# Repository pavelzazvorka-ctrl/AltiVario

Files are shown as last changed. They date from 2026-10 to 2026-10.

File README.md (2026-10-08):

# AltiVario

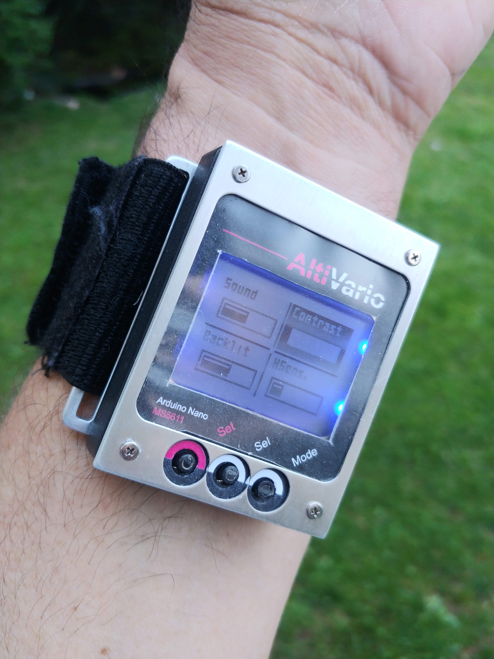
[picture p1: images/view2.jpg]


AltiVario je vario na paragliding. meri a zobrazuje rychlost stoupani/klesani, vysku a posila data pres BT do aplikace XC track na mobilnim telefonu

### Historie:

Cilem hry bylo mit rychle a presne zalozni vario s moznosti exportu zivych dat do aplikace XC track v mobilnim telefonu.
cela akce byla zaroven test mych moznosti a schopnosti zajistit kompletni short-run vyrobu jak HW tak SW. Vyrobil 
jsem celkem deset kusu, ktere jsem vetsinou rozdal znamym. AltiVario opravdu letalo a bylo prakticky pouzitelne.
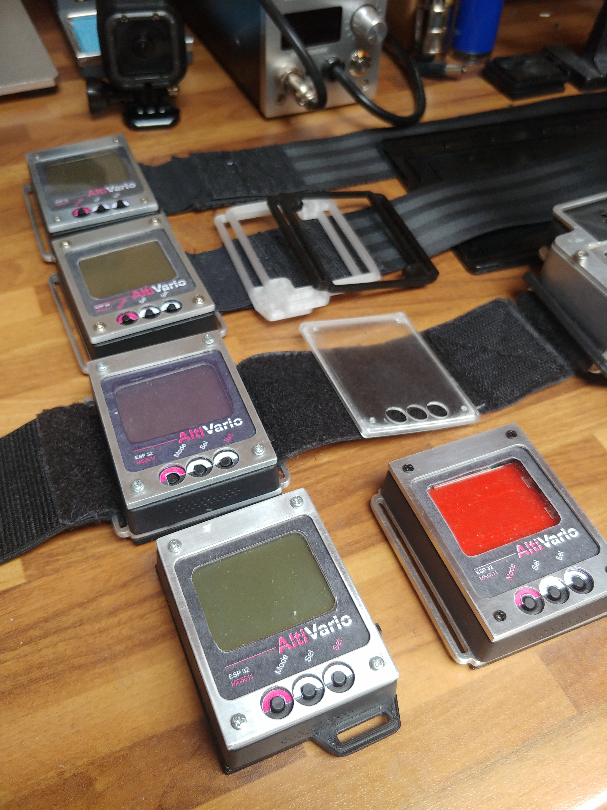
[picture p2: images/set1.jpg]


### HW

vario je postavene nad ESP32 a nejlepsim barometrickym sensorem na trhu MSI5611.Duraz byl kladen hlavne na minimalni
prodlevu a presnost. Soucasti repository jsou i data pro vyrobu PCB ( Eagle ) a CNC G-code data pro frezovani krabicek 
a duralovych ramecku.

Vyvoj byl uspesny, vyroba byla rozumne automatizovana, finalni cena jednoho kusu byla kolem 600 CZK ( viz xls ) 

### SW

Popis SW a celkove ovladani pristore je popsano v Vario.md
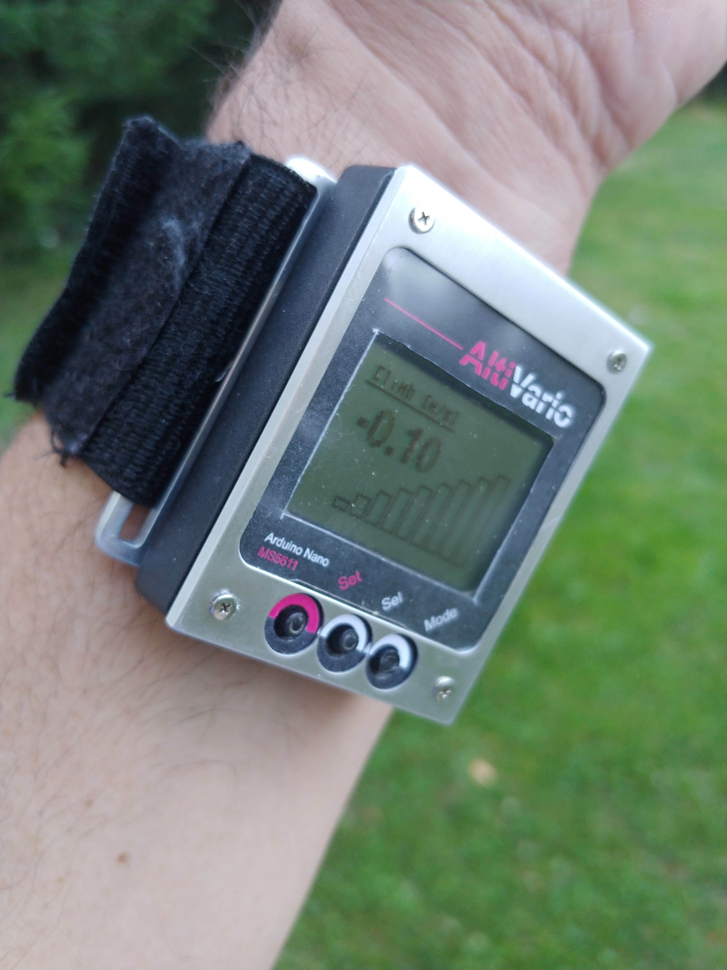
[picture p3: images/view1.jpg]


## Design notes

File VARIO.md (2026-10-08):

# AltiVario – návod k použití

*Pavel, 12. 10. 2021 · Původní dokumentace k verzi softwaru 0.61.*

Stručný návod k ovládání přístroje AltiVario, jeho nastavení, propojení s XCTrack a nabíjení.

> **Poznámka:** Popis odpovídá původní verzi 0.61 z roku 2021. Údaje o výdrži a dostupných funkcích se vztahují k této verzi.

## 1. Úvodní obrazovka a tlačítka

Úvodní obrazovka zobrazuje verzi softwaru a napětí LiPo článku. Na přístroji jsou tři tlačítka: **MODE**, **SEL** a **SET**.

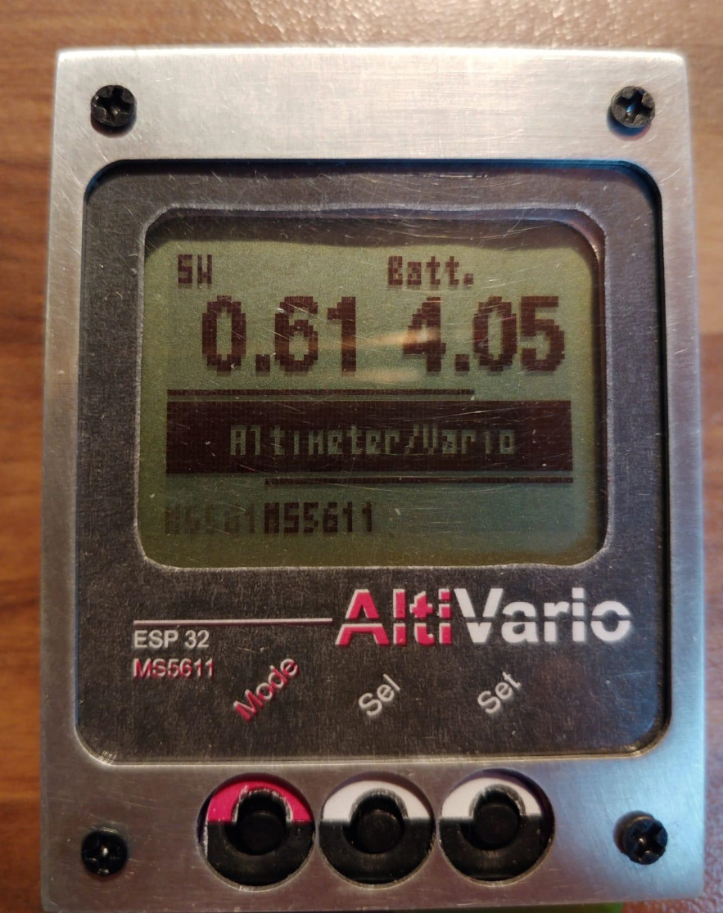
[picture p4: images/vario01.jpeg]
AltiVario – úvodní obrazovka


## 2. Provozní obrazovky

Jednotlivé provozní obrazovky se přepínají **krátkým stiskem MODE**.

### Obrazovka 1 – Výška, vário a graf (varianta 1)

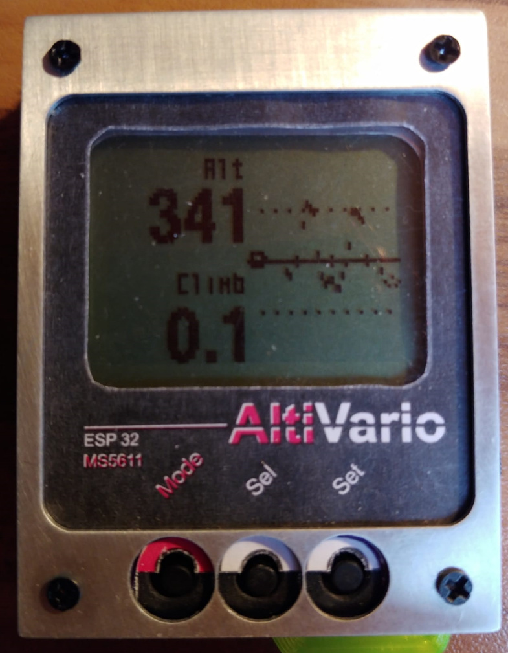
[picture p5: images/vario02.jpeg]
Výška, vário a graf – první rozložení


### Obrazovka 2 – Výška, vário a graf (varianta 2)

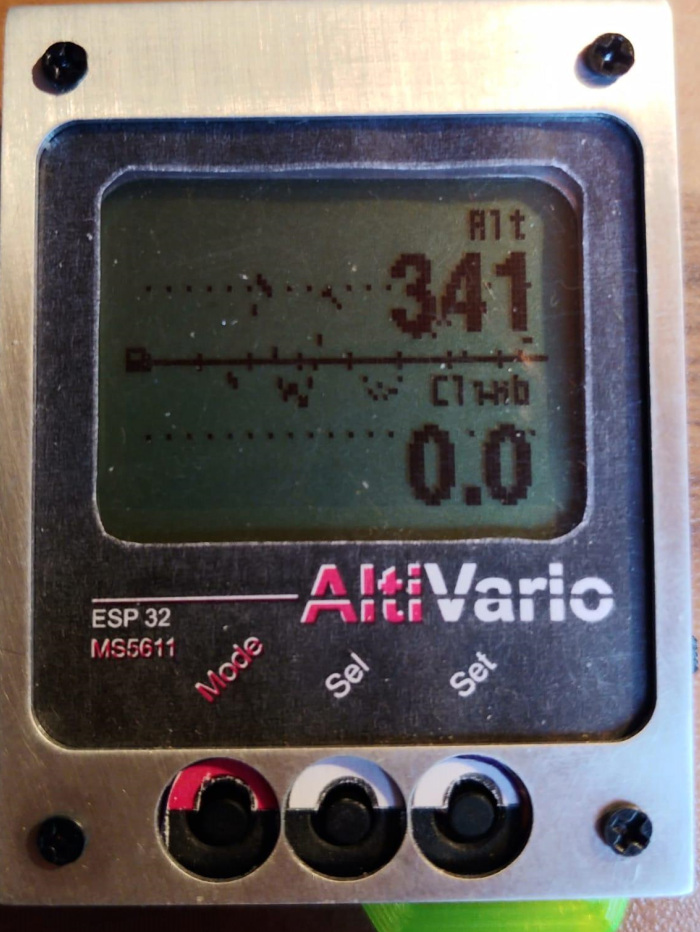
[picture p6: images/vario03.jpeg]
Výška, vário a graf – druhé rozložení


### Obrazovka 3 – Alt, Alt2, čas a vário

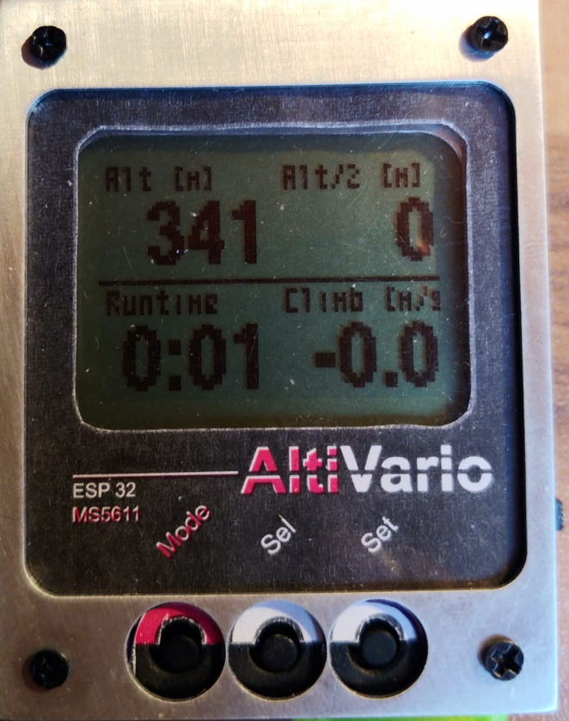
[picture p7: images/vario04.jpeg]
Alt, Alt2, čas a vário


Stisk **SET** na této obrazovce resetuje hodnotu **Alt2**. Typicky se používá k vynulování výšky na zemi.

### Obrazovka 4 – Alt, Alt3, výškový zisk a vário

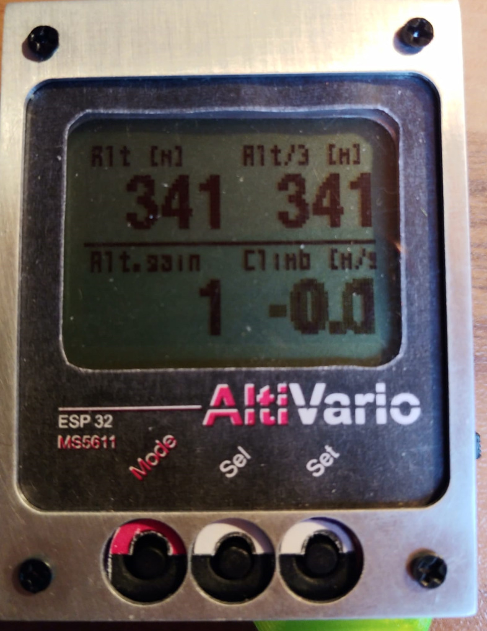
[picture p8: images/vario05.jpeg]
Alt, Alt3, výškový zisk a vário


Stisk **SET** na této obrazovce resetuje hodnotu **Alt3**. Typicky se používá při vlétnutí do stoupavého proudu.

### Obrazovka 5 – Teplota a baterie

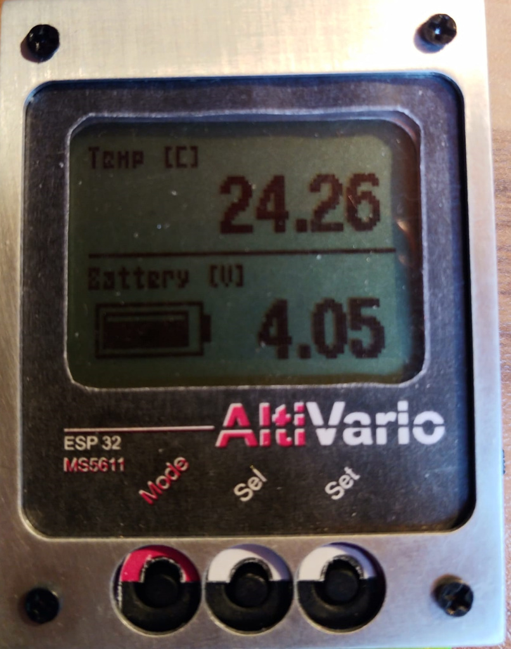
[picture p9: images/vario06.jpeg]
Teplota a napětí baterie


Dlouhým stiskem **SET** na této obrazovce se přístroj přepne do nabíjecího režimu. Změní se kalibrace měření napětí a vypne se zvuková signalizace. Zpět do běžného režimu se lze vrátit pouze vypnutím a opětovným zapnutím přístroje.

## 3. Nastavení

Do nastavení se vstupuje **dlouhým stiskem MODE**. Obsahuje dvě obrazovky, mezi nimiž se přepíná krátkým stiskem **MODE**. Dlouhý stisk **MODE** vrátí přístroj do hlavního režimu.

### 3.1 Referenční výška / tlak a hranice signalizace

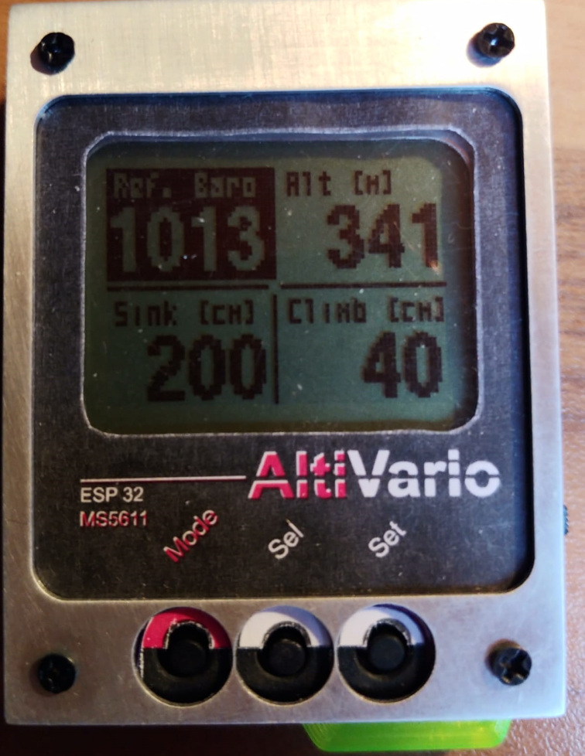
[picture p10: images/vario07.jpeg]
Nastavení referenčního tlaku, výšky a prahů stoupání/klesání


Na první obrazovce lze nastavit referenční tlak v hPa nebo referenční výšku v metrech a prahové hodnoty zvukové signalizace stoupání a klesání (**lift/sink**).

- **SEL** přepíná mezi nastavovanými položkami.
- **SET** zahajuje úpravu vybrané položky.
- Hodnoty se upravují po jednotlivých číslicích pomocí **SEL/SET**.

Příklad zobrazení při úpravě referenční výšky:

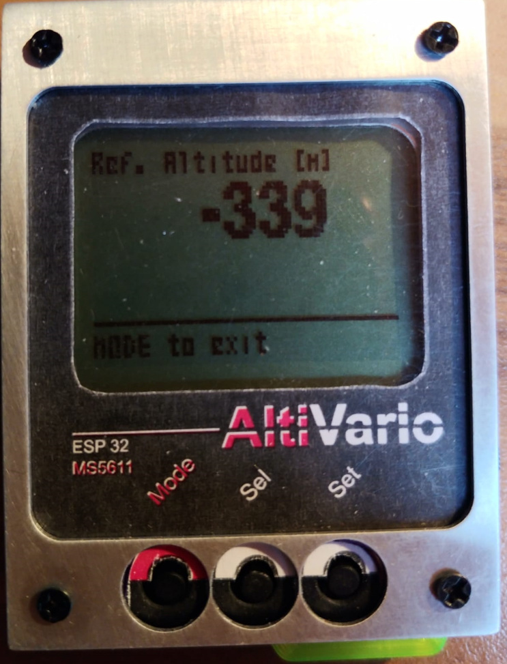
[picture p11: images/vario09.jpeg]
Úprava referenční výšky


### 3.2 Zvuk, kontrast, Bluetooth a citlivost

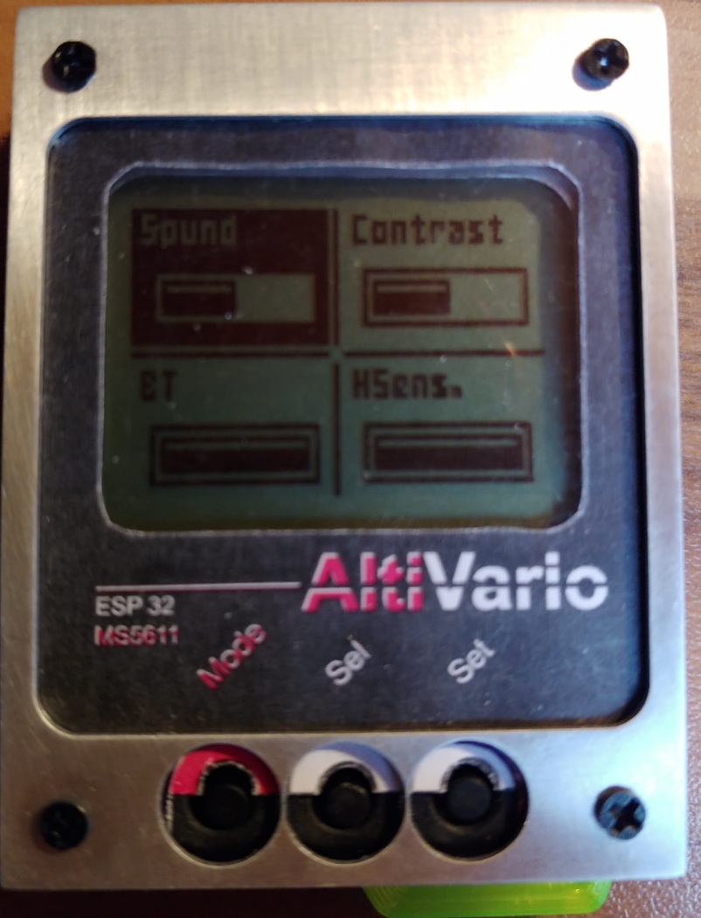
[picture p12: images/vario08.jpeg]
Nastavení zvuku, kontrastu, Bluetooth a citlivosti


Na druhé obrazovce jsou nastavení zobrazená jako posuvné pruhy. Pomocí **SEL** se vybere položka, pomocí **SET** se změní její hodnota.

| Položka | Význam |
| --- | --- |
| **Sound** | Tři režimy: `OFF`, `NORMAL`, `LIVELY AIR`. Poslední režim indikuje drobné pohyby vzduchu kolem nulového stoupání („poklepávání“). |
| **Contrast** | U použitého CZ displeje podle původního návodu nefunguje / není potřeba. |
| **BT** | Položka Bluetooth na obrazovce nastavení; původní text její ovládání blíže nepopisuje. |
| **HSens.** | Příprava na regulaci citlivosti; ve verzi 0.61 ještě není funkční. |

## 4. Propojení s XCTrack

1. V Bluetooth vyhledejte zařízení **BT AltiVario** a spárujte je bez zadání kódu.
2. V aplikaci **XCTrack** otevřete **Connection & Sensors** a vyberte **BT AltiVario**.
3. Zapněte volbu **Use external barometer**.
4. Položka **Calibrate** zobrazí hodnoty měřené variometrem.

V původním návodu je jako příklad uvedeno měření **330,835 ± 0,096 m**; autor tuto hodnotu srovnává s deklarovanou přesností použitého senzoru **MS5611** (přibližně 10 cm).

Doporučuje se přidat na hlavní obrazovku XCTrack údaj **Baro Alt** a před vzletem zkalibrovat tlak podle výšky místa startu.

## 5. Nabíjení

Původní konstrukce nemá automatickou správu nabíjení (*power management*). Nabíjení probíhá přes USB a vyžaduje **sledování napětí baterie**. Autor původního návodu doporučuje slabší napájecí zdroj.

1. Zapněte přístroj.
2. Pomocí **MODE** přejděte na obrazovku s baterií (obrazovka 5).
3. Podržte **SET**, dokud se nezobrazí nabíjecí režim.

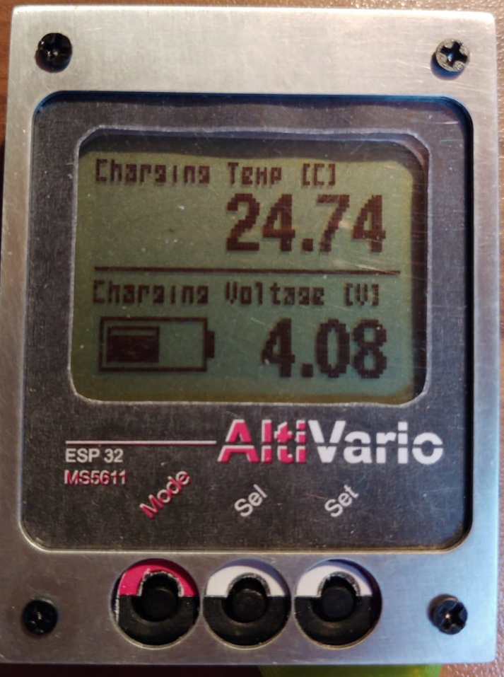
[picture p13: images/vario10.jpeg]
AltiVario – nabíjecí režim


V nabíjecím režimu odpovídá zobrazené napětí lépe skutečnému napětí článku a vário nevydává zvukové signály. Návrat do běžného režimu vyžaduje vypnutí a zapnutí přístroje.

> **Upozornění:** Nabíjecí režim nenahrazuje ochranu LiPo článku ani automatické ukončení nabíjení. Původní dokument výslovně uvádí, že přístroj nemá power management; nabíjení proto vyžaduje odpovídající bezpečné zapojení a dohled.

## 6. Hardware a výdrž

- **Displej:** Nokia
- **Barometrický senzor:** MS5611
- **Procesor:** ESP32 se sníženou frekvencí jádra kvůli spotřebě
- **Odhadovaná výdrž podle původního návodu:** přibližně 6 hodin s Bluetooth, déle bez Bluetooth; u větší baterie autor očekával přibližně 8 hodin.

Firmware verze **0.61** byl podle původního dokumentu dostupný ve zdrojových kódech a bylo jej možné aktualizovat přes USB. Původní Word obsahuje vložený objekt/ikonu ZIP archivu, nikoli ověřený odkaz na repozitář; odkaz na aktuální firmware je potřeba doplnit samostatně.

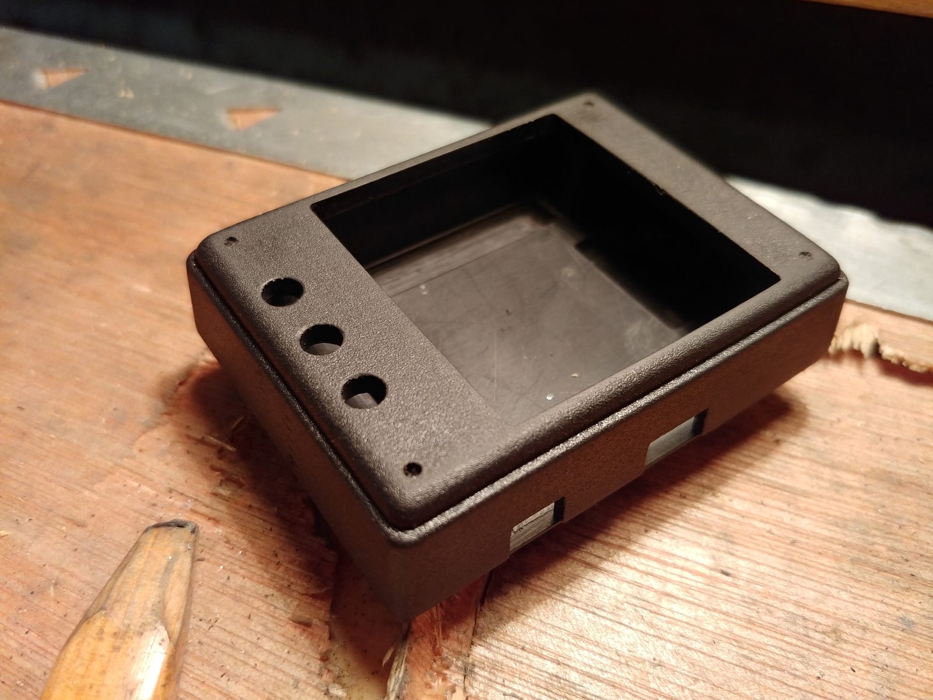
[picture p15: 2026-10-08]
doc/img/20210103_174444_HDR.jpg

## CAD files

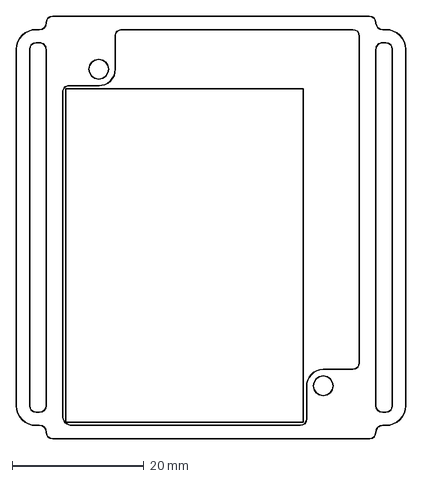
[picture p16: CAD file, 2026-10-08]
cnc/prezka 4.dxf
59.0 x 64.0 mm

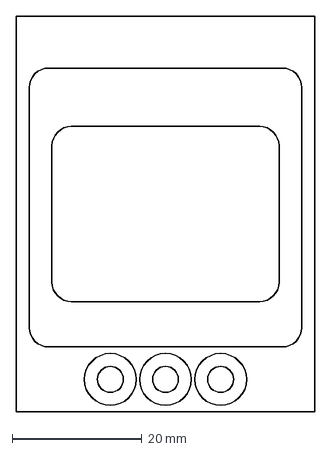
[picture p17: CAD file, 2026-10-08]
cnc/inlay.dxf
46.0 x 61.0 mm

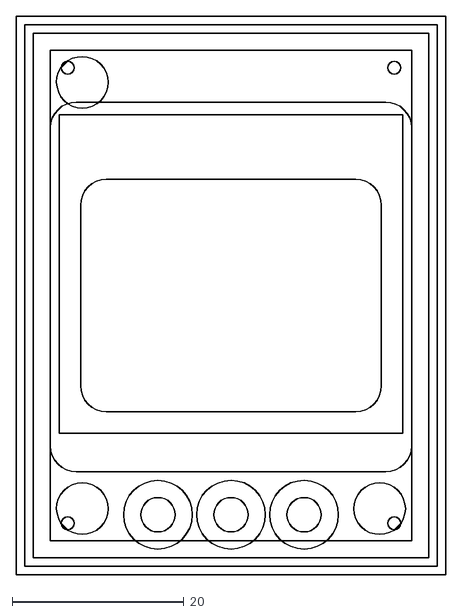
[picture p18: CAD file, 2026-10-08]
cnc/vario.dxf
50.0 x 65.0

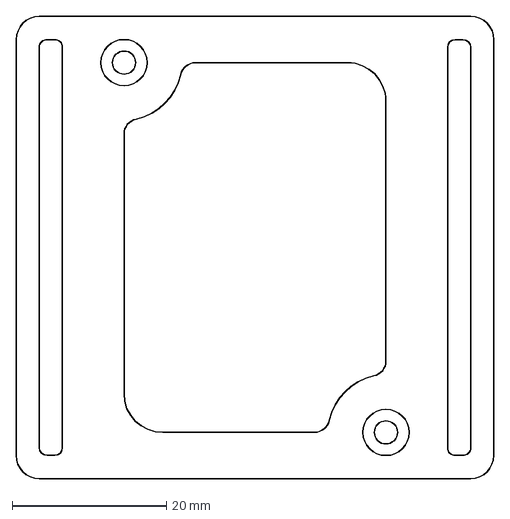
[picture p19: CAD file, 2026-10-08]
cnc/back.dxf
62.0 x 60.0 mm

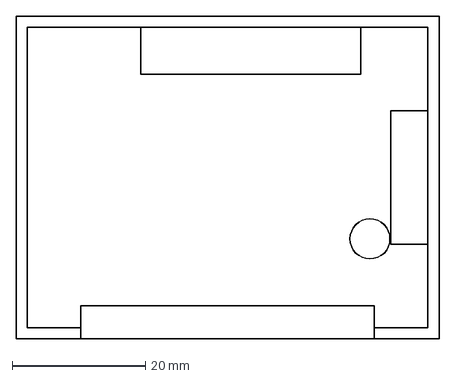
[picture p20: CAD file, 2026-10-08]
cnc/cover.dxf
63.4 x 48.4 mm

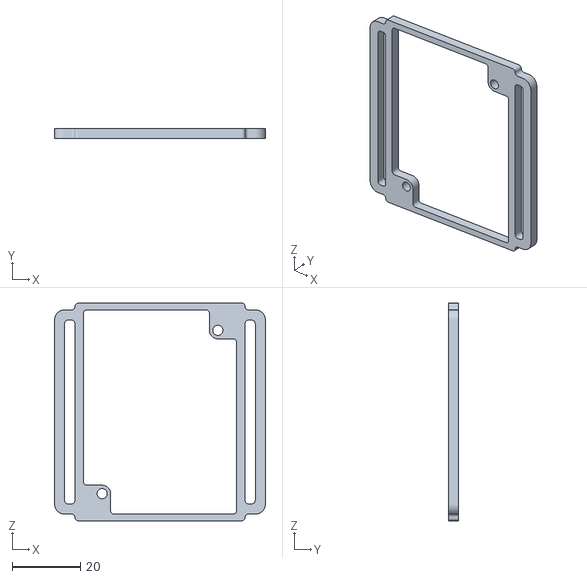
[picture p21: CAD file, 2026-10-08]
cnc/Prezka2.stl
62.0 x 3.00 x 64.0

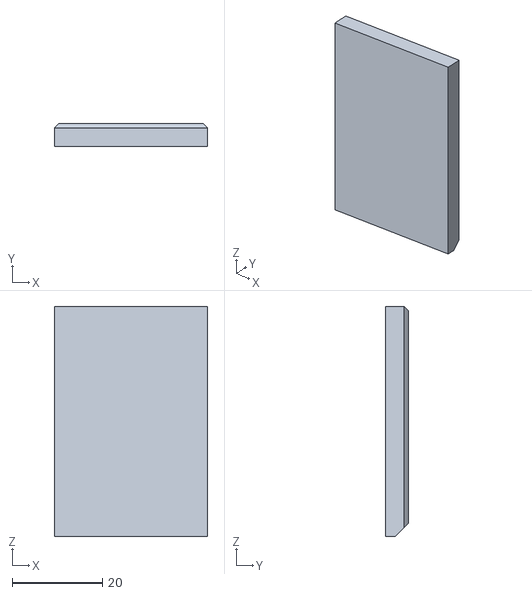
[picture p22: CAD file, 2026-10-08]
cnc/Accu.stl
34.0 x 5.20 x 51.0

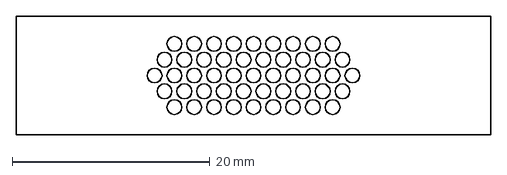
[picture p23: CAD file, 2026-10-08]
cnc/grill.dxf
48.0 x 12.0 mm

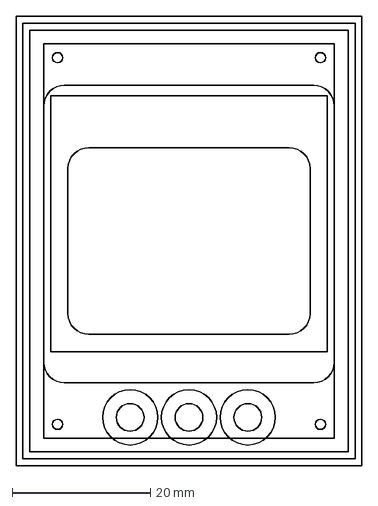
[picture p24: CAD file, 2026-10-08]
cnc/frame.dxf
50.0 x 65.0 mm

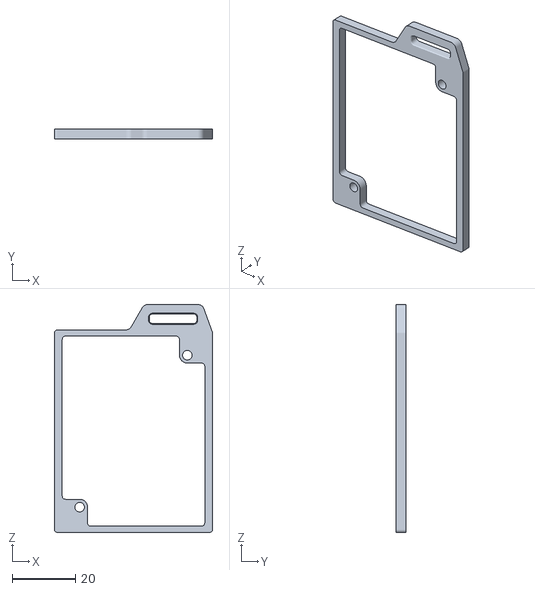
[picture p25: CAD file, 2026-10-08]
cnc/Prezka3.stl
50.0 x 3.00 x 72.0

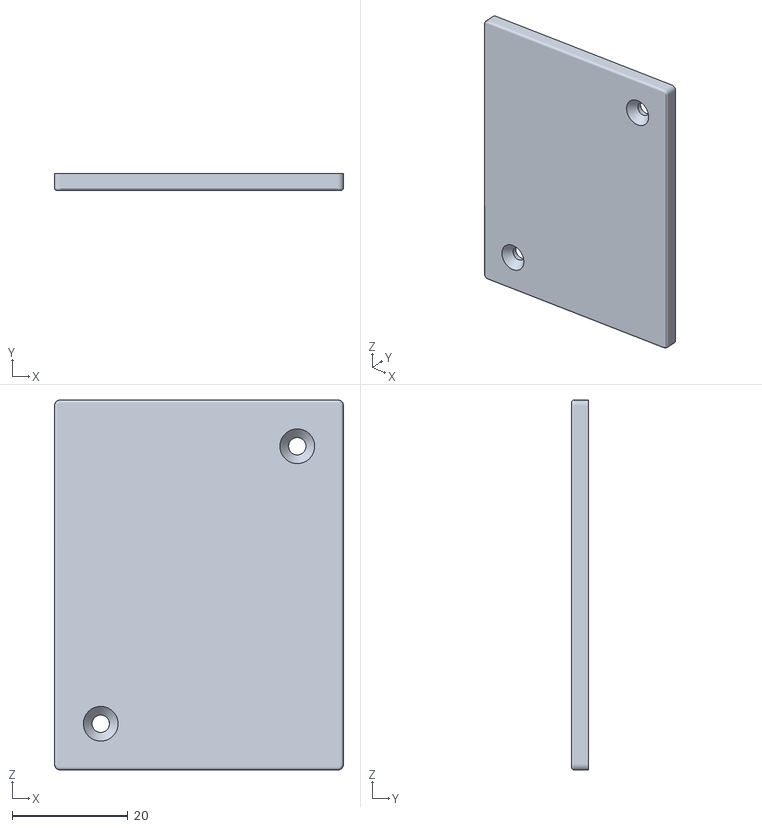
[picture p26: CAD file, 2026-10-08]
cnc/Deklik.stl
50.0 x 3.00 x 64.0

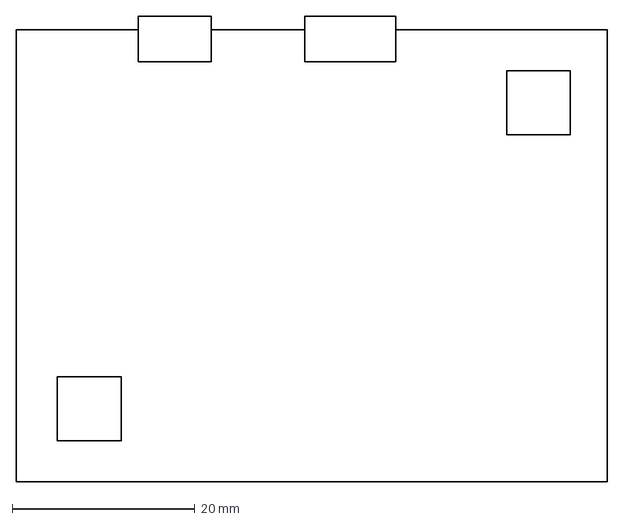
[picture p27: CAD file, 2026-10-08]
cnc/vnitrek.dxf
64.7 x 51.0 mm

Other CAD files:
cnc/Deklik v3.f3d
cnc/Prezka II v7.f3d

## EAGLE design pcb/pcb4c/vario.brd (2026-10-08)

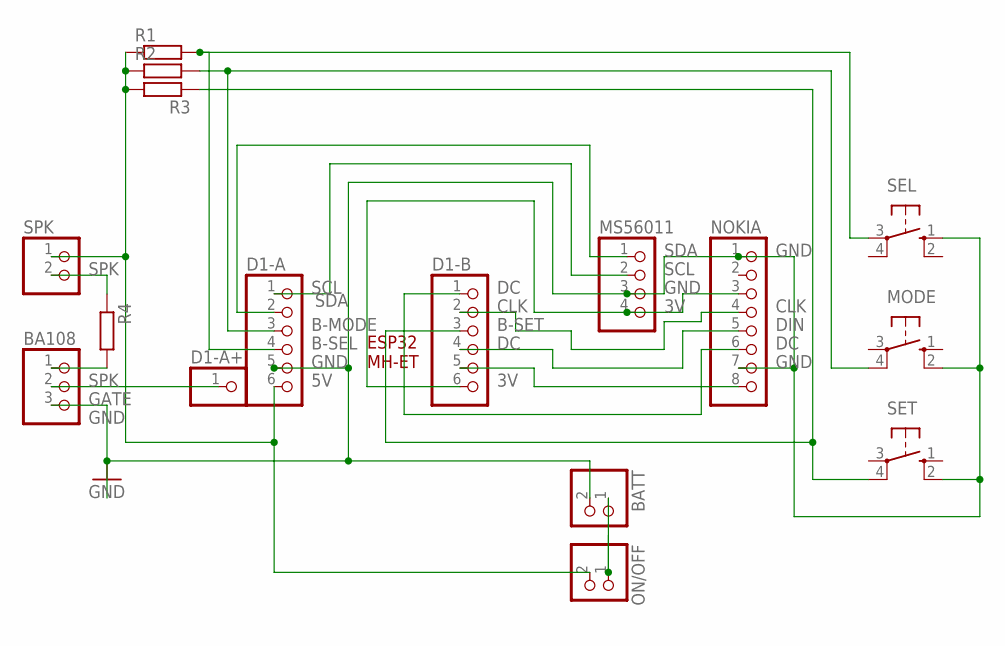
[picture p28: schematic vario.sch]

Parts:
BA108: PINHD-1X3; 1X03
BATT: PINHD-1X2; 1X02
D1-A, D1-B: PINHD-1X6; 1X06
D1-A+: PINHD-1X1; 1X01
MODE: 10-XX; B3F-10XX
MS56011: PINHD-1X4; 1X04
NOKIA: PINHD-1X8; 1X08
ON/OFF: PINHD-1X2; 1X02
R1, R2, R3, R4: R-EU_0207/10; 0207/10
SEL: 10-XX; B3F-10XX
SET: 10-XX; B3F-10XX
SPK: PINHD-1X2; 1X02

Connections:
3V: D1-B.6, MS56011.4, NOKIA.3
5V: D1-A.6, ON/OFF.2, R1.1, R2.1, R3.2, SPK.1
B-MODE: D1-A.3, MODE.4 (P1), R2.2
B-SEL: D1-A.4, R1.2, SEL.3
B-SET: D1-B.3, R3.1, SET.4 (P1)
BATT: BATT.1, ON/OFF.1
CLK: D1-B.2, NOKIA.4
DC: D1-B.1, NOKIA.6
DIN: D1-B.4, NOKIA.5
GATE: BA108.2, D1-A+.1
GND: BA108.3, BATT.2, D1-A.5, MODE.2 (S1), MS56011.3, NOKIA.1, NOKIA.7, SEL.1 (S), SET.2 (S1)
unnamed: R4.1, SPK.2
RST: D1-B.5, NOKIA.8
SCL: D1-A.1, MS56011.2
SDA: D1-A.2, MS56011.1
SPK: BA108.1, R4.2

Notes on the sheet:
ESP32 MH-ET

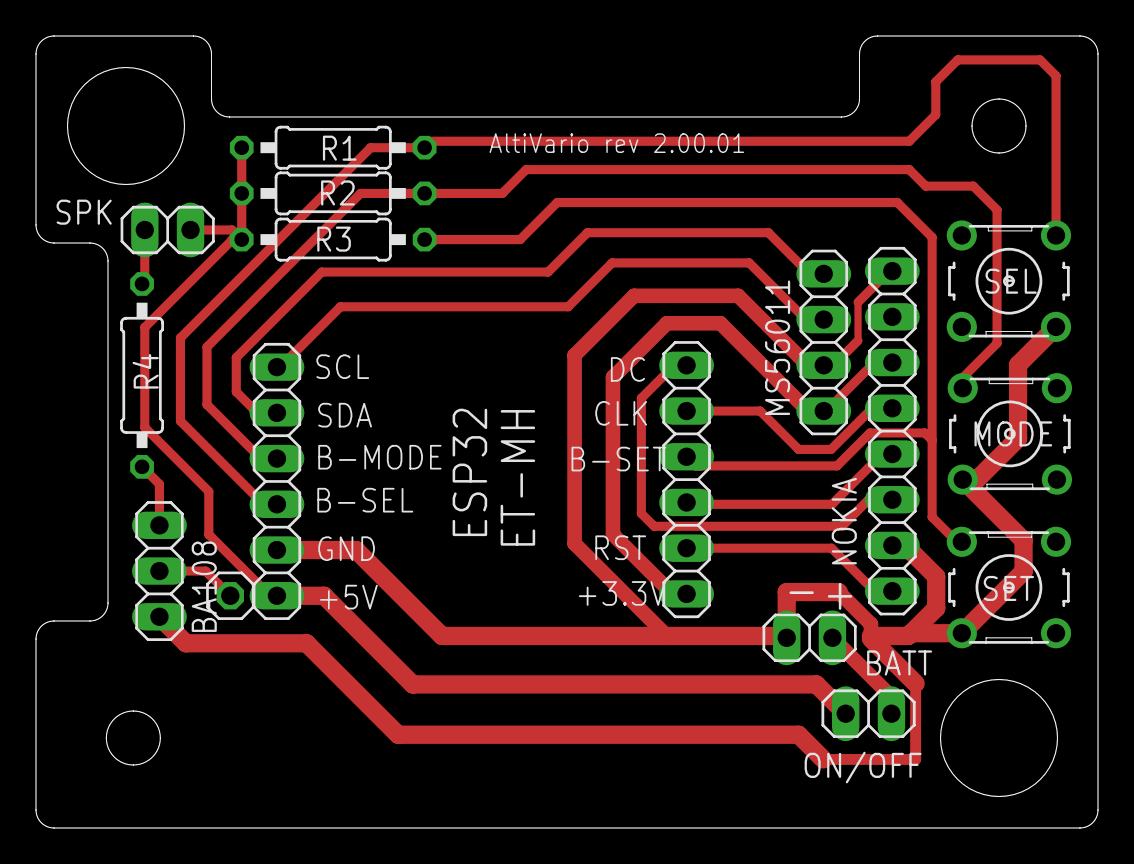
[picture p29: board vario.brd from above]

Board: 2 copper layers, 59.0 x 44.0 mm, 16 parts (0 on the bottom side), 16 nets.

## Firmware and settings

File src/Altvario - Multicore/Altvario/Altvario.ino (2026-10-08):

#define SERIAL_MONITOR
#define SERIAL_MONITOR_KEYS
#define SERIAL_MONITOR_CFG
#define SERIAL_MONITOR_BT

#define SOUND_ON
#define BARO_ON // otherwise EMU
#define DISPLAY_ON 
#define BT_ON // BT is quite an expensive >500 kB flash / 70 mA

#include <Wire.h>
#include "pitch.h"
#include "Vario.h"
#include "Sound.h"
#include "Screen.h"
#include "Key.h"
#include <EEPROM.h>
#include <esp32-hal-cpu.h>
#include <esp32-hal-bt.h>

#ifdef BT_ON
#include "BluetoothSerial.h"
#if !defined(CONFIG_BT_ENABLED) || !defined(CONFIG_BLUEDROID_ENABLED)
#error Bluetooth is not enabled! Please run `make menuconfig` to and enable it
#endif
#endif

#ifdef U8X8_HAVE_HW_SPI
#include <SPI.h>
#endif
#ifdef U8X8_HAVE_HW_I2C
#include <Wire.h>
#endif

#ifdef DISPLAY_ON
#include <U8g2lib.h>
#endif

#ifdef BARO_ON
#include <MS561101BA.h>
static MS561101BA baro = MS561101BA();
#endif

// Vario version
const float ver = 0.61;

const int8_t CE_PIN   = U8X8_PIN_NONE;
const byte ledPin     = U8X8_PIN_NONE;

// ESP32 MH-ET Live
//-------------------------------------------------------------------------
const int8_t RST_PIN  = 05;
const int8_t DC_PIN   = 26;
const int8_t DIN_PIN  = 23;
const int8_t CLK_PIN  = 18;
const int8_t ADC_PIN  = 35;
// I2C SDA (21)
// I2C SCL (22)
const byte sndPin     = 02; // speaker PIN / onboard LED
const byte buttonSet  = 19; // Button #1
const byte buttonSel  = 17; // Button #2
const byte buttonMode = 16; // Button #3

#ifdef DISPLAY_ON
static U8G2_PCD8544 u8g2(U8G2_R0,CE_PIN,DC_PIN,RST_PIN);
#endif

const byte DISPLAY_WIDTH = 84;
const byte DISPLAY_HEIGHT = 48;

// Global classes
static Vario vario;
static Sound sound;
static Screen screen;
static Key key;

// BT
#ifdef BT_ON
BluetoothSerial SerialBT;
#endif

// Global vars
static unsigned long _time = 0;  // timing
static unsigned long _time_0 = 0;  // timing
static unsigned long _time_1 = 0;  // timing
static int dcnt=0;               // Display step
static int bcnt=0;               // BT step
static int scnt=0;               // SND step
//static bool baro_on = true;    // MS5611 on board
static int mode = 0;             // mode of vario (see screen.h)
static int section=0;            // section of vario ( quarters of setup screen )
static int EditorTmpVal=0;       // Temp. value for editor
static char DispVal[5];          // Disp. buffer for editor

hw_timer_t * timer = NULL;
portMUX_TYPE timerMux = portMUX_INITIALIZER_UNLOCKED;
TaskHandle_t TaskUI;
TaskHandle_t TaskSensor;

void readingData()
{
  float rBaro = 1013;
  float rTemp = 20;  

  // Reading of MS5611
  #ifdef BARO_ON
      rTemp = baro.getTemperature(MS561101BA_OSR_4096);  
      rBaro = baro.getPressure(MS561101BA_OSR_4096);      
  #else    
      rBaro = 900 + (0.75 * sin(millis()/5000.00)) + (0.50 * sin(40+millis()/3000.00));
      rTemp = 23.12;
  #endif

  if (rBaro>0) {
    vario.update(rBaro,rTemp);  
    if (scnt-- < 0) {    
        scnt=4;
        #ifdef SOUND_ON
        sound.update(vario.ClimbRate);
        #endif
    }
  }
}

volatile bool get_data;

void loopSensor(void * parameter)
 {
  for(;;)
  {
    if ( get_data ) {
        portENTER_CRITICAL(&timerMux);
        get_data = false;
        portEXIT_CRITICAL(&timerMux);
        readingData();             
        vTaskSuspend(NULL);
    }
  }
}
 
void IRAM_ATTR onTime() {
    portENTER_CRITICAL_ISR(&timerMux);
    get_data = true;
    vTaskResume(TaskSensor);
    portEXIT_CRITICAL_ISR(&timerMux);
}

void loop() 
{
}

void loopUI(void * parameter) 
{    
  for(;;)
{
  // readingData();
  
  #ifdef DISPLAY_ON

  key.poll();        
         
  // process keys on interactive pages    
  switch (mode)
  { 
    case S_SETUP_1:
        if (key.isModeHold()) { // exit
           // save & exit
           mode=0;
        }
        
        if (key.isModePressed()) {
           section=0;
           mode=S_SETUP_2;    
        }
        
        if (key.isSelPressed()) {
           section++;
           if (section>3) section=0;    
        }
        
        if (key.isSetPressed()) {
           mode=S_EDIT;
           switch (section) {
           case 0:
                EditorTmpVal = vario.getZeroPressure();
                break;
           case 1:     
                EditorTmpVal = (int)vario.Altitude;
                break;
           case 2:     
                EditorTmpVal = (int)(vario.Cfg.SinkThreshold);
                break;
           case 3:     
                EditorTmpVal = (int)(vario.Cfg.ClimbThreshold);
                break;             
           }
        }
        break;
        
    case S_SETUP_2:
        if (key.isModeHold()) { // exit
           // save & exit
           mode=0;
        }
        if (key.isModePressed()) {
           section=0;
           mode=S_SETUP_1;    
        }
        
        if (key.isSelPressed()) {
           section++;
           if (section>3) section=0;    
        }
        
        if (key.isSetPressed()) {
           switch (section) {
           case 0:  
                vario.Cfg.BeepStyle++; 
                if (vario.Cfg.BeepStyle>MAX_SOUND) vario.Cfg.BeepStyle=0;
                sound.setSoundStyle(vario.Cfg.BeepStyle);
                writeCfg(vario.Cfg);
                break;
           case 1:     
                vario.Cfg.Contrast++;
               if (vario.Cfg.Contrast>MAX_CONTRAST) vario.Cfg.Contrast=0;
                u8g2.setContrast(vario.Cfg.Contrast*2+115);
                writeCfg(vario.Cfg);
                break;
           case 2:     
                vario.Cfg.BT_protocol++;
                if (vario.Cfg.BT_protocol>MAX_BT_PROTOCOL) vario.Cfg.BT_protocol=0;
                writeCfg(vario.Cfg);
                break;
           case 3:     
                vario.Cfg.Sensitivity++;
                if (vario.Cfg.Sensitivity>MAX_SENS) vario.Cfg.Sensitivity=1;
                writeCfg(vario.Cfg);
                break;             
           }
        }            
        break;
        
    case S_EDIT:
       if (screen.editProcess(&EditorTmpVal,(char *)DispVal,0,&key)) {
          // done && save
          switch (section) {
          case 0:  
                vario.setZeroPressure(EditorTmpVal);
                vario.Cfg.stdpressure = (unsigned int) (vario.getZeroPressure()*100);
                break;
          case 1:     
                vario.setZeroPressure(EditorTmpVal,vario.Pressure,vario.Temperature);
                vario.Cfg.stdpressure = (unsigned int) (vario.getZeroPressure()*100);
                break;
          case 2:     
                vario.Cfg.SinkThreshold=EditorTmpVal;
                sound.setSinkThreshold(vario.Cfg.SinkThreshold);
                break;
          case 3:     
                vario.Cfg.ClimbThreshold=EditorTmpVal;
                sound.setClimbThreshold(vario.Cfg.ClimbThreshold);
                break;             
          }
          mode = S_SETUP_1;
          writeCfg(vario.Cfg);
        }            
        break;
     }

     if (dcnt--<0)
     {        
      dcnt=5; // 200 ms 5x/sec   
      // display    
      unsigned int vcc = readVcc();
      u8g2.firstPage();  
      do {  
        switch (mode)
        {        
          case S_VARIO1:          
          case S_VARIO2:
          case S_VARIO3:
          case S_VARIO4:
          case S_STATUS:
          case S_CHARGE:
              screen.update(mode,section,&vario,vcc/1000.00,ver);
              break;        
          case S_SETUP_1:
          case S_SETUP_2:
              screen.update(mode,section,&vario,vcc/1000.00,ver);
              break;        
          case S_EDIT:
              switch (section) {
              case 0:
                    screen.editShow(DispVal,"Ref. Pressure [hPa]");
                    break;
              case 1:     
                    screen.editShow(DispVal,"Ref. Altitude [m]");
                    break;
              case 2:     
                    screen.editShow(DispVal,"Sink Threshold [cm]");
                    break;
              case 3:     
                    screen.editShow(DispVal,"Climb Threshold [cm]");
                    break;             
              }
              break;
        }
      } while( u8g2.nextPage() );     
     }

  #endif
     
  #ifdef SERIAL_MONITOR
  if (millis() < _time) {
    //Serial.print(" CLIMB "); 
    //Serial.print(vario.ClimbRate);         
    Serial.print(" ,rawALT "); 
    Serial.print(vario.rawAltitude);         
    Serial.print(" ,ALT "); 
    Serial.println(vario.Altitude);             
  }
  #endif  

  #ifdef BT_ON
  if (bcnt-- < 0 && vario.Cfg.BT_protocol>0) {

    if (vario.Cfg.BT_protocol>0)
    {
      
      // LK8000 EXTERNAL INSTRUMENT SERIES 1 - NMEA SENTENCE: LK8EX1
      // VERSION A, 110217

      // LK8EX1,pressure,altitude,vario,temperature,battery,*checksum

      // Field 0, raw pressure in hPascal:
      //  hPA*100 (example for 1013.25 becomes  101325) 
      //  no padding (987.25 becomes 98725, NOT 098725)
      //  If no pressure available, send 999999 (6 times 9)
      //  If pressure is available, field 1 altitude will be ignored     

      // Field 1, altitude in meters, relative to QNH 1013.25
      //  If raw pressure is available, this value will be IGNORED (you can set it to 99999
      //  but not really needed)!
      //  (if you want to use this value, set raw pressure to 999999)
      //  This value is relative to sea level (QNE). We are assuming that
      //  currently at 0m altitude pressure is standard 1013.25.
      //  If you cannot send raw altitude, then send what you have but then
      //  you must NOT adjust it from Basic Setting in LK.
      //  Altitude can be negative
      //  If altitude not available, and Pressure not available, set Altitude
      //  to 99999  (5 times 9)
      //  LK will say "Baro altitude available" if one of fields 0 and 1 is available.

      // Field 2, vario in cm/s
      //  If vario not available, send 9999  (4 times 9)
      //  Value can also be negative

      // Field 3, temperature in C , can be also negative
      //  If not available, send 99
      
      // Field 4, battery voltage or charge percentage
      //  Cannot be negative
      //  If not available, send 999 (3 times 9)
      //  Voltage is sent as float value like: 0.1 1.4 2.3  11.2 
      //  To send percentage, add 1000. Example 0% = 1000
      //  14% = 1014 .  Do not send float values for percentages.
      //  Percentage should be 0 to 100, with no decimals, added by 1000!
      
      bcnt=5; // 250 ms loop (4x sec)

      char tbuf[80];
      unsigned int checksum, ai, bi;                                                     
      sprintf(tbuf,"LK8EX1,%d,%d,%d,%d,%.2f,",(int)(vario.Pressure*100.00),(int)(vario.Altitude),(int)(vario.ClimbRate*100.00),(int)vario.Temperature,readVcc()/1000.00);
      int len = strnlen(tbuf,80);
      for (checksum = 0, ai = 0; ai < len; ai++)
      {
        bi = (unsigned char)tbuf[ai];
        checksum ^= bi;
      }
      sprintf(tbuf,"$LK8EX1,%d,%d,%d,%d,%.2f,*%x",(int)(vario.Pressure*100.00),(int)(vario.Altitude),(int)(vario.ClimbRate*100.00),(int)vario.Temperature,(readVcc()/1000.00),checksum);
      
      #ifdef SERIAL_MONITOR_BT
        Serial.println(tbuf);
      #endif
      SerialBT.println(tbuf);
    }
  }
  #endif

  // keys / loop

  #ifdef DISPLAY_ON
  while (millis() < _time) {
    key.poll();    
    switch (mode) {    
    case S_EDIT:    // leave key handling on SCREEN when S_EDIT
    case S_SETUP_1: // leave key handling on SCREEN when S_EDIT
    case S_SETUP_2: // leave key handling on SCREEN when S_EDIT
    case S_CHARGE:  // Charging - no way out    
        break;
    case S_VARIO1:
    case S_VARIO2: 
    case S_VARIO3:     
    case S_VARIO4:
       if ( key.isSetHold()) {
           #ifdef SERIAL_MONITOR_KEYS    
           Serial.println("AltX RESET");  
           #endif        
           if (mode==S_VARIO1) { vario.offset2=-vario.Altitude; }; // reset Alt2 on first page       
           if (mode==S_VARIO2) { vario.offset2=-vario.Altitude; }; // reset Alt2 on first page       
           if (mode==S_VARIO3) { vario.offset2=-vario.Altitude; }; // reset Alt2
           if (mode==S_VARIO4) { vario.offset3=-vario.Altitude; }; // reset Alt3
        }         
       if ( key.isSelHold()) {
           #ifdef SERIAL_MONITOR_KEYS    
           Serial.println("Stopwatch RESET");  
           #endif        
           if (mode==S_VARIO3) { vario.Stopwatch=millis(); } // reset Stopwatch
       }            
        // pass through def.
    case S_STATUS:
       if ( key.isSetHold()) {
           #ifdef SERIAL_MONITOR_KEYS    
              Serial.println("CHARGE");  
           #endif        
           mode=S_CHARGE; //S_SHOW_BARO;        
           chargingModeOn();
        }             
    default:    
        if (key.isModePressed()) {
           mode++;
           #ifdef SERIAL_MONITOR_KEYS    
           Serial.print("MODE++ ");  
           Serial.println(mode);  
           #endif        
           if (mode>S_STATUS) mode=0;    
        }
        if ( key.isModeHold()) {
           #ifdef SERIAL_MONITOR_KEYS    
           Serial.println("SETUP");  
           #endif        
           mode=S_SETUP_1; //S_SHOW_BARO;
        }
     }
     if (millis() < (_time-10)) {
        delay(10);
     }
  }
  key.done();      
  #endif

  _time += 50; // 50 ms loop (20x sec)
    
}
}

void chargingModeOn()
{
  Serial.print("Charging mode");   

  vario.Cfg.BeepStyle=0;
  sound.setSoundStyle(0);

  Serial.println(" Sound OFF / BT OFF");
  vario.Cfg.BT_protocol=0;
  #ifdef BT_ON
  Serial.println(" Disable BT");
  SerialBT.flush();  
  SerialBT.disconnect();
  SerialBT.end();
  Serial.println(" Disabled BT");   
  #endif
  
  Serial.print("CPU frequency:");   
  //function takes the following frequencies as valid values:
  //  240, 160, 80    <<< For all XTAL types 
  //  40, 20, 10      <<< For 40MHz XTAL
  //  26, 13          <<< For 26MHz XTAL
  //  24, 12          <<< For 24MHz XTAL
  bool cpu = setCpuFrequencyMhz(10);

  int cpuf    = getCpuFrequencyMhz();  // In MHz
  Serial.print(cpuf);   
  Serial.print(" MHz XTAL: ");   
  int xtal = getXtalFrequencyMhz();
  Serial.print(xtal);   
  Serial.println(" MHz");   

  Serial.println(" Running low power");  
}

void setup() 
{ 
  Serial.begin(115200); 
  float rBaro = 900.35;
  float rTemp = 23.12; 

  Serial.print("CPU frequency:");   
  //function takes the following frequencies as valid values:
  //  240, 160, 80    <<< For all XTAL types 
  //  40, 20, 10      <<< For 40MHz XTAL
  //  26, 13          <<< For 26MHz XTAL
  //  24, 12          <<< For 24MHz XTAL
  bool cpu = setCpuFrequencyMhz(80);

  int cpuf    = getCpuFrequencyMhz();  // In MHz
  Serial.print(cpuf);   
  Serial.print(" MHz XTAL: ");   
  int xtal = getXtalFrequencyMhz();
  Serial.print(xtal);   
  Serial.println(" MHz");   

  // Init
  vario.init();
  EEPROM.begin(64);
  readCfg(&(vario.Cfg));  
  Serial.print("Pressure:");  
  vario.setZeroPressure(vario.Cfg.stdpressure/100.00);
  Serial.println(vario.getZeroPressure());
  
  #ifdef BT_ON
  if (vario.Cfg.BT_protocol>0) {
    Serial.println("BT on");
    SerialBT.begin("BT AltiVario"); //Bluetooth device name        
  }
  else
  {
    Serial.println("BT off");
  }
  #else
  Serial.println("BT disabled");
  #endif

  Serial.println("Vario setup");   
  Wire.begin();
  Wire.setClock(400000); // 10000 low speed // 100000 standard // 400000 fast mode
  
  #ifdef BARO_ON
    baro.init(MS561101BA_ADDR_CSB_LOW); 
  #endif  
  
  sound.init(sndPin,&(vario.Cfg));
  
  #ifdef DISPLAY_ON
  
    screen.init(&u8g2);
    key.init(sndPin,buttonMode,buttonSel,buttonSet);
  
    // GFX init
    u8g2.begin();
    u8g2.setFontRefHeightExtendedText();
    u8g2.setDrawColor(1);
    u8g2.setFontPosBaseline(); // Top
    u8g2.setFontDirection(0);
    
    u8g2.setDrawColor(1);         // pixel on
    u8g2.setContrast(vario.Cfg.Contrast*2+115);
  #endif

  hwsetup();  

  // delay and buffers initial update update  
  delay(1000);
  #ifdef BARO_ON
      rTemp = baro.getTemperature(MS561101BA_OSR_4096);  
      rBaro = baro.getPressure(MS561101BA_OSR_4096);      
  #endif
  for (int i=0;i<100;i++)
  {  
    if (rBaro>0) {vario.update(rBaro,rTemp);    
    } 
  }

  _time=millis();
  _time_0=millis();
  
  xTaskCreatePinnedToCore(loopSensor, "loopSensor", 10000, NULL, 1, &TaskSensor,  1);   
  xTaskCreatePinnedToCore(loopUI, "loopUI", 10000, NULL, 1, &TaskUI,  0); 

  timer = timerBegin(0, 80, true);
  timerAttachInterrupt(timer, &onTime, true);
  timerAlarmWrite(timer, 4000, true); // 4ms loop
  timerAlarmEnable(timer);
}

// **********************************************************************************

long readVcc() {
  long result = 4150; // system_get_vdd33();
  result = analogRead(ADC_PIN)*1.71;  
  return result;
}

void DrawWelcomeScreen(float Vcc, float Ver,int stp) 
{
#ifdef DISPLAY_ON  
  char vcc[10];
  dtostrf(Vcc,1,2,vcc);

  char ver[10];
  dtostrf(Ver,1,2,ver);

  u8g2.setFont(FONT_MICRO);
  u8g2.drawBox(0, 26, 84, 12);
  u8g2.setDrawColor(0);
  u8g2.drawStr( 13, 35, "Altimeter/Vario");
  u8g2.setDrawColor(1);
  u8g2.drawStr( stp*2-36, 48, "MS5611");
  
  u8g2.drawHLine(48-stp, 39, 84);  
  u8g2.drawHLine(0, 24, stp+36);  

  screen.setupCharSection(false, 0, 0,42,"SW",ver);
  screen.setupCharSection(false,44, 0,42,"Batt.",vcc);
#endif  
}

int batNote[] = {NOTE_C4, NOTE_D4, NOTE_E4, NOTE_F4, NOTE_G4};
int batLevel[] = {3500, 3750, 3900, 4050, 4200};

void hwsetup() {
  
  //if (ledPin != U8X8_PIN_NONE)
  //{
  //pinMode(ledPin, OUTPUT);
  //analogWrite(ledPin,255);      
  //}
    
  int vcc = readVcc();

  Serial.print("Vcc:");
  Serial.print(vcc);
  Serial.println(" mV");
  
  // Voltage soundcheck
  for (int i = 0; i < 5; i++) {    
    if (vcc > batLevel[i]) {
      #ifdef SOUND_ON
      tone(sndPin, batNote[i], 150,0);
      #endif
    } else {
      #ifdef SOUND_ON
      tone(sndPin, batNote[i], 50,0); 
      #endif
    }
    for (int ii = 0; ii < 5; ii++) {    
#ifdef DISPLAY_ON        
    u8g2.firstPage();  
    do {
      DrawWelcomeScreen(vcc/1000.00,ver,i*10+ii*2); 
    } while( u8g2.nextPage() );
#else
    delay(300);
#endif    
    }
  }  
  delay(1000);
}

// EEPROM somehow cant be located in VarioCfg

void writeCfg( VarioCfg cfg )
{
    #ifdef SERIAL_MONITOR_CFG
    Serial.println("cfg write");    
    Serial.print("cfg.SinkThreshold ");
    Serial.println(cfg.SinkThreshold);
    Serial.print("cfg.ClimbThreshold ");
    Serial.println(cfg.ClimbThreshold);
    Serial.print("cfg.Sensitivity ");
    Serial.println(cfg.Sensitivity);    
    Serial.print("cfg.BeepStyle ");
    Serial.println(cfg.BeepStyle);
    Serial.print("cfg.Contrast ");
    Serial.println(cfg.Contrast);
    Serial.print("cfg.BT_protocol ");
    Serial.println(cfg.BT_protocol);
    Serial.print("cfg.stdpressure ");
    Serial.println(cfg.stdpressure);
    // Serial.print("cfg.ChartSpeed ");
    // Serial.println(cfg.ChartSpeed);    
    #endif        

    int val  = 0;
    val = (unsigned int)EEPROM.read(0); if (val != cfg.SinkThreshold)  EEPROM.write(0,(unsigned byte)(cfg.SinkThreshold));   
    val = (unsigned int)EEPROM.read(1); if (val != cfg.ClimbThreshold) EEPROM.write(1,(unsigned byte)(cfg.ClimbThreshold));    
    val = (unsigned int)EEPROM.read(2); if ((unsigned int)val != cfg.Sensitivity)   EEPROM.write(2,(unsigned byte)(cfg.Sensitivity));    
    val = (unsigned int)EEPROM.read(3); if ((unsigned int)val != cfg.BeepStyle)     EEPROM.write(3,(unsigned byte)(cfg.BeepStyle));
    val = (unsigned int)EEPROM.read(4); if ((unsigned int)val != cfg.Contrast)      EEPROM.write(4,(unsigned byte)(cfg.Contrast));    
    val = (unsigned int)EEPROM.read(5); if ((unsigned int)val != cfg.BT_protocol)   EEPROM.write(5,(unsigned byte)(cfg.BT_protocol));
    //val = (unsigned int)EEPROM.read(6); if ((unsigned int)val != cfg.ChartSpeed)    EEPROM.write(6,(unsigned byte)(cfg.ChartSpeed));

    // stdpressure mutlibyte
    byte four = (cfg.stdpressure & 0xFF);
    byte three = ((cfg.stdpressure >> 8) & 0xFF);
    byte two = ((cfg.stdpressure >> 16) & 0xFF);
    byte one = ((cfg.stdpressure >> 24) & 0xFF);
    EEPROM.write(7, four);
    EEPROM.write(8, three);
    EEPROM.write(9, two);
    EEPROM.write(10, one);
    
    EEPROM.commit();
}
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

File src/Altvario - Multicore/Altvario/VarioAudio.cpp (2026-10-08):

#include <Arduino.h>
#include "VarioAudio.h"
#include "config.h"

void VarioAudio::analogWrite(int pin, uint32_t value)
{
  ledcAttachPin(pin, audiochannel_);
  ledcWrite(audiochannel_, value);
}

void VarioAudio::analogWriteFreq(double freq)
{
  ledcWriteTone(audiochannel_, freq);
}

void VarioAudio::Config(int pinPWM, int audiochannel,VarioCfg *cfg) {  
  sinkToneCps_       	=  -(cfg->SinkThreshold);  // SINK_THRESHOLD -200
  climbToneCps_      	=  cfg->ClimbThreshold; // CLIMB_THRESHOLD 30
  liftyAirToneCps_   	=  cfg->ZeroThreshold;  // ZERO_THRESHOLD -80
  varioState_ 		    =  VARIO_STATE_QUIET;
  discrimThreshold_   =  cfg->DisrciminationThreshold; // CLIMB_DISCRIMINATION_THRESHOLD 25
  beepPeriodTicks_	  = 0;
  beepEndTick_ 		    = 0;
  beepCps_ 			      = 0;
  varioCps_ 			    = 0;
  freqHz_  			      = 0;
  pinPWM_ 			      = pinPWM;
  audiochannel_		    = audiochannel;
  analogWrite(pinPWM_, 0);
}

void VarioAudio::VarioBeep(int32_t nCps,int beepStyle) 
{
  // beepPeriodTicks_ 30 is full period
  // beepEndTick_ = 2;

  // There is running loop incrementing tick++ and decrementing beepPeriodTicks_--
  // Once beepEndTick>ticks is shut the tone off
  // beepPeriodTicks_ kick in the half ... 

  // Table for time slots is defined in VarioAudio.h
  // table for beep duration and repeat rate based on vertical speed (stale at 8 m/s)
  // BEEP beepTbl_[10] = {{13,4},{11,4},{9,4},{8,4},{7,4},{6,4},{5,3},{4,2},{3,1},{3,1},};  
  
  int32_t newFreqHz = 0;

  if (
    (beepPeriodTicks_ <= 0)
    ||   ((tick_ >= beepPeriodTicks_ / 2) && (ABS(nCps - varioCps_) > discrimThreshold_)) // check if we are in the middle of interval & and change bigger than 25
    ||   ((nCps >= climbToneCps_) && (varioCps_ < climbToneCps_))                         // check if we just broke the limit for ascend
    ||   (beepStyle>1) && ((nCps >= liftyAirToneCps_) && (varioCps_ < liftyAirToneCps_))  // or check if we just broke the limie for lifty air (if it is configured)
  ) 
  {
    varioCps_ = nCps;

    // if sinking much faster than glider sink rate, generate continuous tone alarm
    if (varioCps_ <= sinkToneCps_) {   // we are in the area where we should indicate sink
      varioState_ = VARIO_STATE_SINK;
      beepCps_ = varioCps_;
      if (beepCps_ < -VARIO_MAX_CPS) { // limit max sink tone (10 m/s)
        beepCps_ = -VARIO_MAX_CPS;
      }
      tick_ = 0;
      if (beepCps_ == -VARIO_MAX_CPS) { // if we went to the limit use a special tune
        beepPeriodTicks_ = 10;
        beepEndTick_ = 10;
        newFreqHz = offScaleLoTone_[0];
        freqHz_ = newFreqHz;
        SetFrequency(freqHz_);
      }
      else { // sinking, but still within limits
        beepPeriodTicks_ = 20;
        beepEndTick_  = 18;
        newFreqHz = VARIO_SINK_FREQHZ + ((sinkToneCps_ - beepCps_) * (VARIO_MAX_FREQHZ - VARIO_SINK_FREQHZ)) / (VARIO_MAX_CPS + sinkToneCps_); // calculation of sinking frequency
        //           base frequency                                       adjust the frequency range according to define range   
        CLAMP(newFreqHz, VARIO_MIN_FREQHZ, VARIO_MAX_FREQHZ); // restrict frequency by physical capabilities of the speaker
        freqHz_ = newFreqHz;
        SetFrequency(freqHz_);
      }
    }

    //if climbing, generate beeps
    else {

      if (varioCps_ >= climbToneCps_) {
        varioState_ = VARIO_STATE_CLIMB;
        beepCps_ = varioCps_;
        if (beepCps_ > VARIO_MAX_CPS) { // limit maximum lift to (10 m/s)
          beepCps_ = VARIO_MAX_CPS;
        }
        tick_ = 0;
        if (beepCps_ == VARIO_MAX_CPS) { // if we went over the limit, play a special tune
          beepPeriodTicks_ = 10;
          beepEndTick_ = 10;
          newFreqHz = offScaleHiTone_[0];
          freqHz_ = newFreqHz;
          SetFrequency(freqHz_);
        }
        else {

          // Time table / length lookup table to set beep timeframe
          int index = beepCps_ / 100;
          if (index > 9) index = 9;
          beepPeriodTicks_ = beepTbl_[index].periodTicks;
          beepEndTick_ = beepTbl_[index].endTick;
          
          if (beepCps_ > VARIO_XOVER_CPS) {
            newFreqHz = VARIO_XOVER_FREQHZ + ((beepCps_ - VARIO_XOVER_CPS) * (VARIO_MAX_FREQHZ - VARIO_XOVER_FREQHZ)) / (VARIO_MAX_CPS - VARIO_XOVER_CPS); // calculation for climb
          }
          else {
            newFreqHz = VARIO_MIN_FREQHZ + (beepCps_ * (VARIO_XOVER_FREQHZ - VARIO_MIN_FREQHZ)) / VARIO_XOVER_CPS; // calculation for lifty air
          }
          CLAMP(newFreqHz, VARIO_MIN_FREQHZ, VARIO_MAX_FREQHZ);
          freqHz_ = newFreqHz;
          SetFrequency(freqHz_);
        }
      }
      else   // in "lifty-air" band, indicate with a ticking sound with longer interval
        if ((beepStyle>1) && (varioCps_ >= liftyAirToneCps_)) 
        {
          varioState_ = VARIO_STATE_LIFTY_AIR;
          beepCps_ = varioCps_;
          tick_ = 0;
          beepPeriodTicks_ = 30;
          beepEndTick_ = 2;
          newFreqHz = VARIO_TICK_FREQHZ + (beepCps_ * (VARIO_XOVER_FREQHZ - VARIO_TICK_FREQHZ)) / VARIO_XOVER_CPS;
          CLAMP(newFreqHz, VARIO_TICK_FREQHZ, VARIO_MAX_FREQHZ);
          freqHz_ = newFreqHz;
          SetFrequency(freqHz_);  // higher frequency as you approach climb threshold          
        }

      // not sinking enough to trigger alarm,  be quiet
        else {
          varioState_ = VARIO_STATE_QUIET;
          tick_ = 0;
          beepPeriodTicks_ = 0;
          beepEndTick_  = 0;
          freqHz_ = 0;
          SetFrequency(freqHz_);
        }
    }
  }
  else {
    tick_++;
    beepPeriodTicks_--;
    newFreqHz = freqHz_;
    if (tick_ >= beepEndTick_) { // shut off tone
      newFreqHz = 0;
    }
    else if (beepCps_ == VARIO_MAX_CPS) {
      newFreqHz = offScaleHiTone_[tick_]; // offscale Hi table tone sequence as we reached the limit
    }
    else if (beepCps_ == -VARIO_MAX_CPS) {
      newFreqHz = offScaleLoTone_[tick_]; // offscale Lo table tone sequence as we reached the limit
    }
    else if (varioState_ == VARIO_STATE_SINK) {
      newFreqHz = freqHz_ - 10;
    }
    if (newFreqHz != freqHz_) { // update frequency when needed
      freqHz_ = newFreqHz;
      SetFrequency(freqHz_);
    }
  }
}

void VarioAudio::SetFrequency(int32_t fHz) {
  if (fHz ) {

    analogWriteFreq(fHz);
    analogWrite(pinPWM_, 512);
  }
  else {
    analogWrite(pinPWM_, 0);
  }
}

void VarioAudio::GenerateTone(int32_t fHz, int ms) {
  SetFrequency(fHz);
  delay(ms);
  SetFrequency(0);
}

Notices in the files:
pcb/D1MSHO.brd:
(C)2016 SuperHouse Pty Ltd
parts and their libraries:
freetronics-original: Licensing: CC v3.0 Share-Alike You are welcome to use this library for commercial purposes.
